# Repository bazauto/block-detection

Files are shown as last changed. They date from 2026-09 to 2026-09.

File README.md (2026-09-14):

# 2-Channel DCC Block Detector (Active High)

CT-based occupancy detection for the Westgate Hollow layout. Two independent
channels, each turning the current in an external current transformer into a
push-pull logic level: **HIGH (3.3 V) = block occupied, LOW (0 V) = clear**.

Single +3.3 V rail, fed in through the output header. Board is **48 × 38 mm**,
2 layers, four M2 mounting holes.

## Why build this

**So that a broken cable or connection under the layout doesn't register as a
clear block.**

The off-the-shelf detectors used so far are active low: they pull their output to
0 V when a block is occupied, and leave it open when clear. The feedback node's
inputs are pulled up, so a broken wire floats high, and that reads exactly like a
clear block, the permissive state (`bazauto/layout-feedback#9`).

This board is **active high**: occupied drives 3.3 V, clear drives 0 V. A broken
wire into a pulled-up input now floats to the *occupied* side.

## Status

**Revision 1.0: 10 boards ordered from PCBWay, awaiting delivery.** Nothing has
been measured on hardware yet.

---

## Files

| File | What it is |
|---|---|
| `bazauto-block-detection.kicad_sch` | Schematic (KiCad 10 format) |
| `bazauto-block-detection.kicad_pcb` | 2-layer PCB, fully routed |
| `bazauto-block-detection.kicad_sym` | Project symbols: `TLV9002IDGKR`, `TLV3212IDGKR` |
| `sym-lib-table` | Project symbol library table. There is no project footprint table: every footprint comes from the stock KiCad libraries and is stored in the board file |
| `bom.csv` | Bill of materials, grouped |
| `fab/rev-1.0/` | **Revision 1.0 as sent to fab**: Gerbers, drill files, Gerber job file, position file, the zipped Gerber set, and `SOURCE.txt` fingerprinting the board they came from. See [Fabrication revisions](#fabrication-revisions) |
| `BOM_PCBWay_bazauto-block-detection.xlsx` | **Not in the repo.** `bom.csv` poured into PCBWay's template, ready to upload. Generate it locally; see [Regenerating](#regenerating) |
| `scripts/` | Generators and checkers — see [Regenerating](#regenerating) |

Everything else (resistors, caps, diodes, connectors, trimmers) comes from the
stock KiCad 10 libraries, so the project opens on any standard install.

---

## Circuit

Each channel is the same chain:

```
CT ─ terminal block ─ burden ─ ESD clamp ─ 1k ─ precision peak detector ─ comparator ─ OUT
     J1 / J2          R1,R2,R3  D1 / D2   R4/R5   U1 + D3/D4 + C3/C4 + R8/R9   U2      J3
                      + JP1
```

**Burden.** The CT secondary is loaded across the input terminals.
Channel 1 is switchable, channel 2 is fixed:

| Channel | JP1 | Burden | Use |
|---|---|---|---|
| 1 | open | 1.1 kΩ | Programming track (service-mode ACK pulse) |
| 1 | fitted | 1.1 k ∥ 110 R = **100.0 Ω** | Standard track |
| 2 | — | 100 Ω fixed | Standard track only |

The parallel combination is exact: 1100 × 110 / 1210 = 100.0 Ω.

**Clamp.** D1/D2 (BAT54S, series pair) clamp the input to roughly −0.3 V /
+3.6 V. R4/R5 (1 k) then limit the current into the op-amp's input structure on
the negative half-cycle — the CT output is bipolar and a single-supply op-amp
input sits at the very edge of its absolute maximum without them.

**Peak detector.** The op-amp drives D3/D4 with the diode *inside* the feedback
loop, so the forward drop is divided out by the loop gain — no 0.6 V loss on a
signal this small. R6/R7 (100 Ω) sit between the op-amp output and the diode:
they are inside the loop too, and stop the RRIO output from ringing into the
10 µF hold capacitor. C3/C4 hold the envelope, R8/R9 bleed it away.

**Comparator.** The envelope goes to +IN, the trimmer wiper to −IN, and the
push-pull output drives the header directly. R10/R11 (10 M) add positive
feedback so the output does not chatter as the envelope crosses the threshold.

---

## Setting up

Time constants and tuning, all measurable on the board:

- **Release time.** R8/R9 × C3/C4 = 100 kΩ × 10 µF ≈ **1 s** to decay. That
  doubles as debounce for dirty wheels. For a faster release drop the bleed
  resistor — 10 k gives ≈ 100 ms.
- **Hysteresis.** V_hyst ≈ 3.3 V × R_bleed / R_hyst = 3.3 × 100 k / 10 M
  ≈ **33 mV**. Lower R10/R11 for more.
- **Threshold.** With the block clear, turn RVn until OUTn just goes low, then
  back off about 10 %.

Test points, all on the top side:

| TP | Net | Use |
|---|---|---|
| TP1 / TP3 | VREF1 / VREF2 | Trimmer wiper — the threshold you have dialled in |
| TP2 / TP4 | ENV1 / ENV2 | Peak-detector output — the rectified envelope |
| TP5 | GND | Scope ground |

---

## ⚠ Known concerns with revision 1.0

**1. The signal chain has no gain, and that makes the threshold hard to set.**

This is the one thing worth changing. The detector is a unity-gain rectifier, so
the comparator threshold has to be set in the millivolt region. With a 1:100 CT
and a 100 Ω burden, 10 mA of track current gives about 10 mV at the envelope
node. The trimmer spans the full 0–3.3 V across 10 kΩ, so 10 mV is **0.3 % of
its travel** — a fraction of one turn on a 12-turn trimmer — and it is the same
order as the comparator's own input offset voltage. Setting it repeatably will
be unpleasant, and it will drift.

The cheap fix is one resistor: put ~330 kΩ in series between +3V3 and the top of
each trimmer (RV1 pin 1, RV2 pin 1). The wiper then covers roughly 0–100 mV
instead of 0–3.3 V, giving about 30× the resolution and swamping nothing else.
The alternative is to give the op-amp stage gain instead of running it at unity.

**Revision 1.0, as ordered, does not include this change** (there is no 330 kΩ
part in `bom.csv`). Sizing it properly needs the CT's actual turns ratio. It
affects two nets and about 4 mm of track.

**2. Verify the TLV3212IDGKR pinout against the datasheet.** The comparator
symbol uses the industry-standard 8-pin dual layout — 1=OUTA, 2=INA−, 3=INA+,
4=GND, 5=INB+, 6=INB−, 7=OUTB, 8=V+ — which is what TLV3202IDGKR uses in the
same DGK package. I could not confirm TLV3212's pin assignment from a datasheet
in this session. **TLV3202IDGKR is a verified drop-in** if you would rather not
check. Same for TLV9002IDGKR, though that one follows the universal dual-op-amp
pinout and is not in doubt.

**3. AGND is the plane, not a separate net.** The spec asked for the filter
returns to go to AGND *and* for a solid, unbroken ground plane. Those pull in
opposite directions — a genuine second net needs a split, and a split is exactly
what section 6 forbids. I used one continuous GND pour and kept the analog
returns physically local instead: C3/C4 and R8/R9 ground through their own vias
straight into the plane, a few millimetres from the op-amp's own ground via.

---

## Layout

- **B.Cu is a ground pour.** F.Cu carries the signals plus a second GND pour in
  the gaps. 30 ground vias tie the two together: 16 taking SMD ground pads
  straight down to the plane, 14 stitching the pours across the board.
- **+3V3** runs as a perimeter ring (top edge, right edge, bottom edge) with a
  spine threaded through the gap between the two pad rows of U1 and U2, so it
  never crosses a channel's signal path.
- The two channels are mirrored top and bottom about the board centreline, with
  the shared dual op-amp and comparator between them. Both ICs are rotated so
  channel A faces the top band and channel B the bottom.
- 0.1 µF decoupling (C1, C2) sits against each IC's V+ pin; C5 is the 10 µF bulk.

**Where the ground plane is interrupted.** Four short bottom-layer hops let
crossing nets pass each other, 8.60 mm of track in total on a 1824 mm² board:

| Net | From → to | Length |
|---|---|---|
| +3V3 | (20.20, 22.00) → (20.20, 24.00) | 2.00 mm |
| /OUT1 | (42.20, 18.30) → (43.80, 18.30) | 1.60 mm |
| /OUT2 | (31.90, 22.60) → (33.45, 22.60) | 1.55 mm |
| OA2 out | (21.50, 22.75) → (21.50, 26.20) | 3.45 mm |

`scripts/check_plane.py` audits this and reports which analog nets pass over a
void. Current result: **the CT input rails, both op-amp inputs, ENV1 and VREF1
have completely unbroken copper beneath them.** Four crossings remain, all in
channel 2's middle band — ENV2 twice, VREF2 once, channel 2's op-amp output
once — and in each the trace crosses a void under 1 mm wide. Those nets carry a
rectified DC envelope and a DC threshold reference, where a sub-millimetre
detour in the return path at DCC frequencies is not a real effect. If you want them gone, the honest fix is a 4-layer stack-up, not
more clever 2-layer routing.

One placement change from your version: **C1 moved 0.65 mm right** (to x = 23.45)
so that channel 2's feedback trace and op-amp output each get their own corridor
past it. Everything else is where you left it.

---

## Regenerating

Run with KiCad's bundled Python, from the project directory:

```sh
K="C:/Program Files/KiCad/10.0"

python scripts/gen_schematic.py         # schematic + project symbol lib
python scripts/verify_netlist.py        # netlist vs. design intent
"$K/bin/python.exe" scripts/route_pcb.py    # routing + pours (placement is preserved)
"$K/bin/python.exe" scripts/check_board.py  # placement + board-vs-schematic nets
"$K/bin/python.exe" scripts/check_plane.py  # ground-plane audit
```

`route_pcb.py` loads the existing board, so hand-adjusted placement and
silkscreen survive; it only rebuilds tracks, vias and zones.

| Script | Does |
|---|---|
| `gen_schematic.py` | Builds the schematic from real KiCad library symbols; wires are computed from actual pin coordinates |
| `kicadlib.py` | S-expression reader/writer and symbol-library helpers |
| `probe_transform.py` | Derives KiCad's symbol placement transform empirically from its own demo files |
| `verify_netlist.py` | Compares the extracted netlist against the intended one, net by net |
| `route_pcb.py` | Routing, ground pours, silkscreen legends |
| `check_board.py` | Courtyard overlaps, off-board parts, board nets vs. schematic |
| `check_plane.py` | Bottom-layer voids and which analog nets cross them |
| `make_pcbway_bom.py` | Fills PCBWay's BOM template; fails if it has drifted from `bom.csv`. Needs PCBWay's sample BOM template saved locally as `Sample_BOM_PCBWay.xlsx`. It's PCBWay's file, so it isn't committed, and neither is the output. |
| `check_fab_outputs.py` | Checks the newest `fab/rev-X.Y/` against the board it was generated from; `--record` writes that revision's `SOURCE.txt`. Plain Python, needs `kicad-cli` on PATH or `KICAD_CLI` set |

---

## Fabrication revisions

Each set of files sent to a board house lives in its own `fab/rev-X.Y/` folder
and is never regenerated in place, so the repo always holds exactly what a
revision was. Each revision is also tagged in git (`rev-1.0`).

`fab/rev-X.Y/SOURCE.txt` records the SHA-256 of the board file (line endings
normalised) that its outputs came from. CI runs `scripts/check_fab_outputs.py`:

- **Board unchanged since the newest revision:** it regenerates the outputs and
  fails if the committed ones differ. That catches Gerbers left stale after a
  board edit, and a zip that disagrees with the loose files. Gerbers are compared
  by the geometry they draw, because KiCad doesn't write primitives in a stable
  order.
- **Board changed:** work on the next revision is under way. It reports a notice
  and passes.

To cut a new revision, for example 1.1:

1. Plot Gerbers, drill files (Excellon, PTH and NPTH separate) and the position
   file (CSV, mm, both sides) into `fab/rev-1.1/`, and zip the Gerbers, the
   Gerber job file and the drill files as `bazauto-block-detection.zip` there.
2. `python scripts/check_fab_outputs.py --record rev-1.1`
3. `python scripts/check_fab_outputs.py`, which must report all outputs matching.
4. Land it through a PR, then tag the merge commit `rev-1.1`.

---

## Verification

Everything below was run against the files in this directory:

```
kicad-cli sch erc            0 errors, 0 warnings
verify_netlist.py            all 17 nets match design intent, no unconnected pins
kicad-cli pcb drc            0 violations, 0 unconnected items
check_board.py               37 footprints, 0 problems (no overlaps, nets match schematic)
check_plane.py               8.60 mm bottom-layer track; 4 analog crossings (see above)
```

CI re-runs the two `kicad-cli` checks and `check_fab_outputs.py` on every pull
request (see `.github/workflows/ci.yml`). DRC there runs with `--schematic-parity` at error
severity. At warning severity the parity check reports 80 cosmetic mismatches:
footprints saved without their library prefix, and field text such as a
Datasheet of `''` against `~`. None is a net or connection mismatch.

Gerbers and drill files for revision 1.0 are in `fab/rev-1.0/`, and regenerating
them from the current board reproduces them exactly. Nothing has been measured on
hardware yet. The threshold-resolution concern above is analysis, not a bench
result.

---

## Licence

Copyright © 2026 Paul Barrett.

| Material | Licence |
|---|---|
| **The hardware design**: schematic, board, project symbol library, BOM, Gerbers and drill files, and the enclosure model (`enclosure/`, except `check_fit.py`) | [CERN-OHL-P-2.0](LICENSE) |
| **Software**: everything in `scripts/`, and `enclosure/check_fit.py` | [MIT](LICENSE-MIT) |

Source location: <https://github.com/bazauto/block-detection>

Third-party material, notably the KiCad library symbols the project symbols are
derived from, is listed in [THIRD-PARTY-NOTICES.md](THIRD-PARTY-NOTICES.md).

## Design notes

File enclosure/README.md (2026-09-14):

# Enclosure — 2-Channel DCC Block Detector

3D-printed DIN-rail box for the 48 × 38 mm block-detector PCB in the parent
directory. Three parts, all printable without supports.

**Outer size 62.0 × 52.0 × 32.6 mm**, plus the rail clip underneath.

| Part | STL | Prints |
|---|---|---|
| Box body | `stl/block-detector-base.stl` | floor down, as modelled |
| Lid | `stl/block-detector-lid.stl` | outside face down, as modelled |
| DIN TH35 clip | `stl/block-detector-clip.stl` | mating face down, as modelled |

Everything comes from one parametric source, `block-detector-enclosure.scad`.
`check_fit.py` audits the clearances against the actual KiCad board.

---

## How it goes together

The rail runs along the box's **52 mm axis**, so modules stack side by side
along the rail and every cable leaves through an end wall, not into the
neighbouring module.

- **Left wall** — two slots, one per CT terminal block. J1/J2 are Phoenix PT
  push-in blocks with the wire entry facing the wall, 5 mm behind it. Thread
  the CT leads through the slot before landing them.
- **Right wall** — one slot for the OUT cable, sitting high enough that the
  1×4 housing on J3 passes underneath it and the wires turn out over the top.
- **Board** sits on four 5 mm standoffs, 7 mm above the floor, screwed down at
  its own M2 holes. 22 mm of clear height above it.
- **Lid** has a register lip and four countersunk M3 screws into corner posts.
  Solid — take it off to set the thresholds on RV1/RV2 or move the MODE jumper.

### Hardware

| Qty | Screw | Into |
|---|---|---|
| 4 | M3 × 10 countersunk, self-tapping | lid → corner posts (2.5 mm pilot) |
| 4 | M2 × 6 pan head, self-tapping | board → standoffs (1.6 mm pilot) |
| 2 | M3 × 8 countersunk, self-tapping | DIN clip → box floor (2.5 mm pilot) |

Plain machine screws work as well as self-tappers — they cut their own thread
in the printed pilot holes. Do not over-torque the M2s; the standoffs are
5 mm tall and 5 mm across.

### The DIN clip

Screws to the outside of the box floor, so the box can be re-mounted flat later
by printing a different back plate. One hook is fixed, the other is a 35 mm
spring tongue with a release tab at one end — hook the fixed side over the rail
first, then push until the tongue snaps home. To remove, lever the tab away
from the rail with a small screwdriver.

The channel is 34.6 mm across a 35 mm rail, so the tongue is preloaded and the
module does not rattle. Clipping on needs 2.2 mm of tongue throw.

**Print the clip in PETG** if you have it. The tongue is a living spring and PLA
loses that over time.

---

## Print settings

0.2 mm layers, 3 perimeters, 4 top/bottom, 30 % infill. No supports on any part
— every overhang is either a 45° chamfer or a bridge under 13 mm.

The lid is designed to print with the **outside face on the bed**, so the
lettering is engraved rather than raised and comes out crisp on the first
layers. The `part="lid"` and `part="clip"` outputs are already in their print
orientation; drop the STLs straight into the slicer.

---

## Re-cutting the model

```sh
SCAD="/c/Program Files/OpenSCAD/openscad.exe"

# view it
"$SCAD" block-detector-enclosure.scad

# the printable parts
for p in base lid clip; do
  "$SCAD" -o "stl/block-detector-$p.stl" -D "part=\"$p\"" block-detector-enclosure.scad
done

# check nothing collides after changing a parameter
python check_fit.py
```

`part` also takes `assembly` (box + lid + clip + board + rail), `fit` (board in
the open box) and `section_x` / `section_y` with `section_at` for cutaways.

### Parameters worth touching

| Parameter | Default | Why you would change it |
|---|---|---|
| `headroom` | 22 | Clear height over the board. Set by the 1×4 Dupont housing on J3 (~17 mm) plus room for the wires to turn. Solder the OUT cable straight to the pins and 12 is enough — that takes 10 mm off the box height. |
| `pcb_gap` | 4.6 | Board edge to wall. Driven by the corner posts having to miss the board corners; below ~4.3 they clash. |
| `corner_r` | 4.5 | Outer corner radius. The lid screws sit on this axis, so it also sets the wall left around their countersinks. Do not go below ~4.4 with M3. |
| `spring_preload` | 0.5 | How hard the DIN tongue bears on the rail. Raise it if the module rattles, lower it if it will not clip on. |
| `rail_brim_t` | 1.0 | Rail sheet thickness. Heavy rail is 1.35 — set it and the hooks follow. |

`check_fit.py` reads these straight out of the `.scad`, so run it after any
change. Current result:

```
Enclosure  62.0 x 52.0 x 32.6 mm outer   (interior 57.2 x 47.2 x 28.6)
Board sits 7.0 mm above the floor, 22.0 mm clear above it under the lid.
read 28 component courtyards from the board file
all 37 checks pass
```

Tightest clearances it reports: 0.54 mm between each corner post and the board
corner, 3.77 mm from the M2 screw heads to the RV1/RV2 courtyards, and 1.30 mm
of wall outboard of the lid countersinks.

---

## Not done

Nothing has been printed or measured. The connector heights used to size the
box are nominal — in particular `headroom` assumes a generic 2.54 mm Dupont
housing at about 17 mm above the board. Measure yours before printing; it is
one parameter and the box height follows it directly.

The CT slots assume the Phoenix PT-1,5-2-3.5-H wire axes sit about 4.5 mm above
the board. The slots are 7.5 × 8.5 mm and centred on that, so a couple of
millimetres either way is absorbed.

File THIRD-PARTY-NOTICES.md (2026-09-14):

# Third-party notices

## KiCad libraries: CC-BY-SA 4.0, with a design exception

The schematic and board use symbols and footprints from the stock KiCad 10 libraries, by the KiCad Libraries Team
(<https://gitlab.com/kicad/libraries>). Those libraries are licensed under
[CC-BY-SA 4.0](https://creativecommons.org/licenses/by-sa/4.0/) with this exception:

> To the extent that the creation of electronic designs that use 'Licensed Material' can be considered to be
> 'Adapted Material', then the copyright holder waives article 3 of the license with respect to these designs and any
> generated files which use data provided as part of the 'Licensed Material'.

So the design itself and its generated files (Gerbers, drill files, position file) carry no CC-BY-SA obligation, and
are licensed under CERN-OHL-P-2.0 as stated in the README.

### Project symbols derived from KiCad library symbols

`bazauto-block-detection.kicad_sym` is generated by `scripts/gen_schematic.py`. It copies two stock symbols, renames
them, and changes their properties:

| Project symbol | Derived from |
|---|---|
| `TLV9002IDGKR` | `Amplifier_Operational:LM2904` |
| `TLV3212IDGKR` | `Comparator:MCP6562` |

These are attributed here as adaptations of KiCad library material (KiCad Libraries Team, CC-BY-SA 4.0). The design
exception above very likely covers a symbol library generated for this design, but attribution costs nothing and
holds under either reading.

## Not in the repository

- **PCBWay's BOM template** (`Sample_BOM_PCBWay.xlsx`) and the upload BOM generated from it are PCBWay's format with
  no licence to redistribute, so both are git-ignored and kept locally. `bom.csv` is the source of truth.
- **PCBWay order paperwork** (`PCBWay/`) is git-ignored.

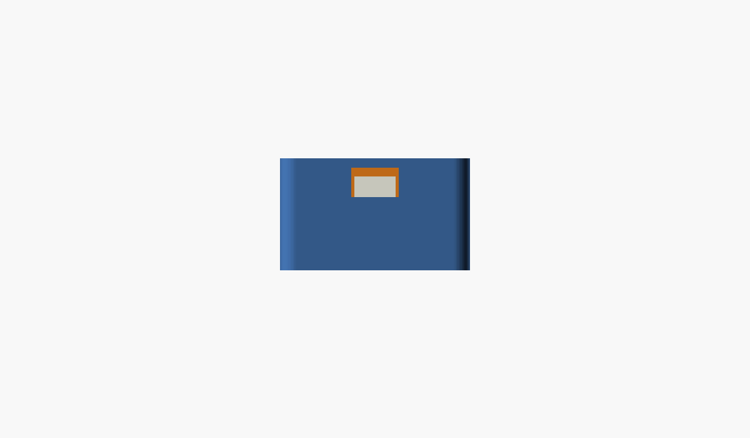
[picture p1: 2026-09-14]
enclosure/previews/fit_right.png

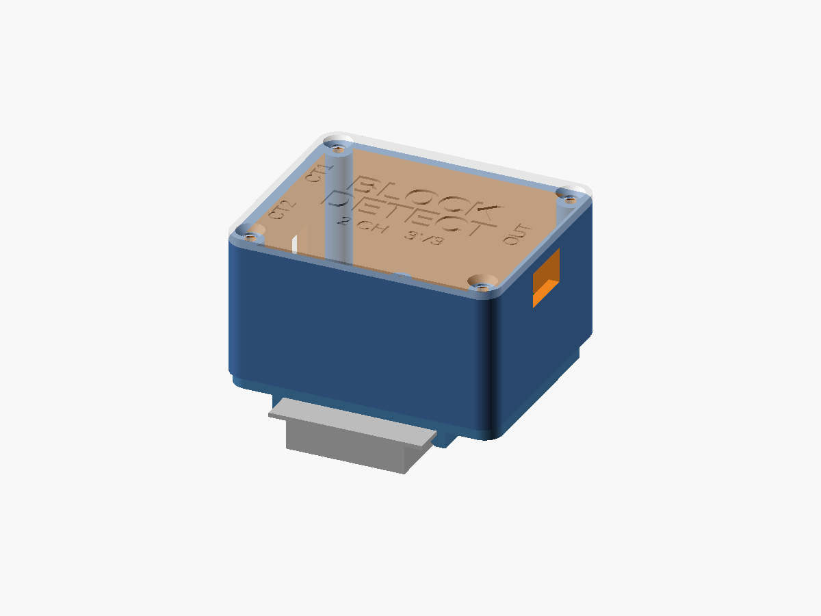
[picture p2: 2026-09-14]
enclosure/previews/asm_iso2.png

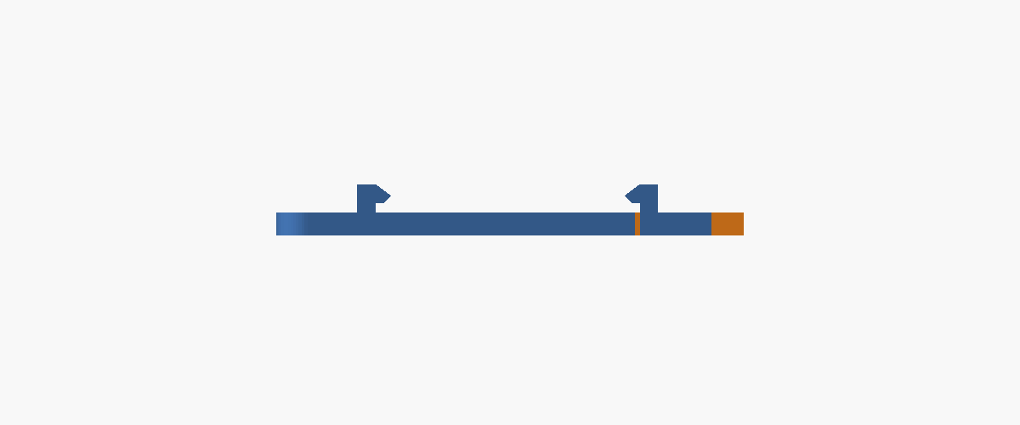
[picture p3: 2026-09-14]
enclosure/previews/clip_end.png

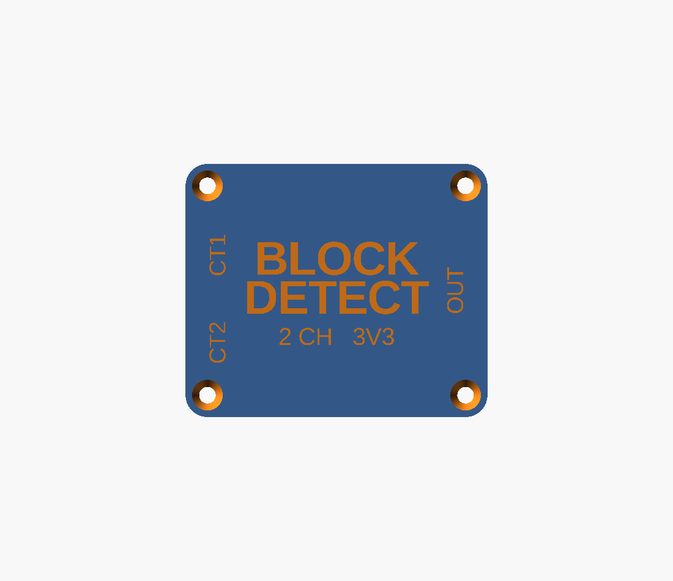
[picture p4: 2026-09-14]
enclosure/previews/lid_top.png

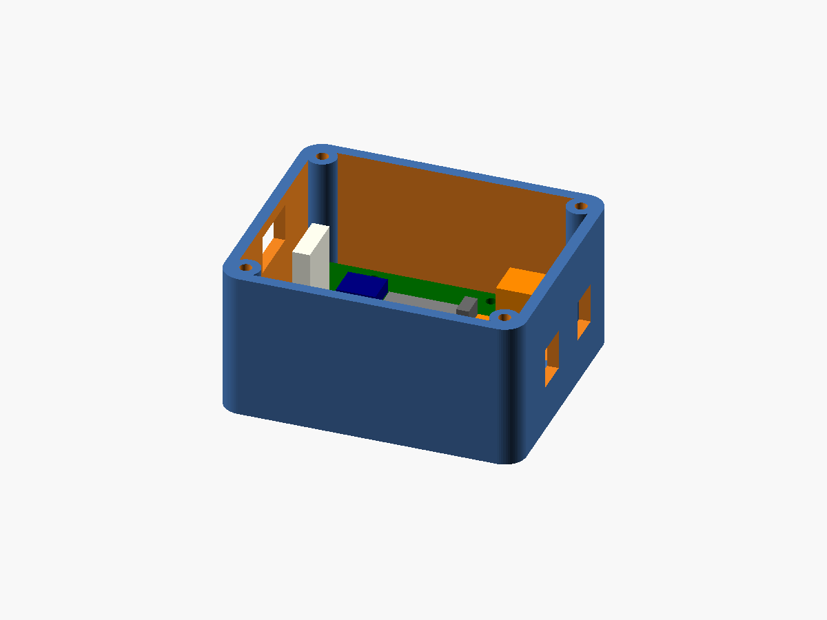
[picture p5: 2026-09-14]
enclosure/previews/fit_iso.png

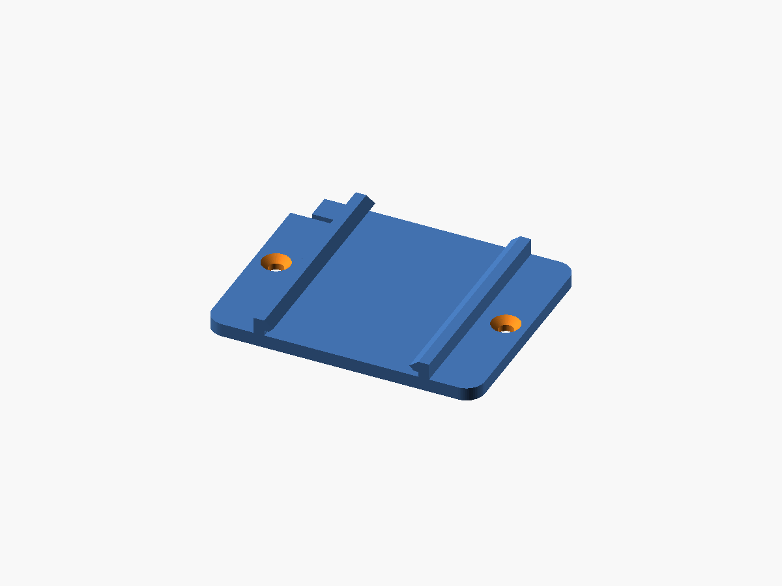
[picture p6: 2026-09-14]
enclosure/previews/clip_iso.png

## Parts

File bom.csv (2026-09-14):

Refs | Value | Footprint | Tolerance | Rating | Description | Alternative Part Number
C1,C2 | 100nF | Capacitor_SMD:C_0805_2012Metric |  | 25V
C3-C5 | 10uF | Capacitor_SMD:C_0805_2012Metric |  | 25V
D1,D2 | BAT54S | Package_TO_SOT_SMD:SOT-23
D3,D4 | 1N4148W | Diode_SMD:D_SOD-123
J1 | CT1 In | TerminalBlock_Phoenix:TerminalBlock_Phoenix_PT-1,5-2-3.5-H_1x02_P3.50mm_Horizontal
J2 | CT2 In | TerminalBlock_Phoenix:TerminalBlock_Phoenix_PT-1,5-2-3.5-H_1x02_P3.50mm_Horizontal
J3 | OUT | Connector_PinHeader_2.54mm:PinHeader_1x04_P2.54mm_Vertical
JP1 | MODE | Connector_PinHeader_2.54mm:PinHeader_1x02_P2.54mm_Vertical
R1 | 1.1k | Resistor_SMD:R_1206_3216Metric | 1%
R2 | 110R | Resistor_SMD:R_1206_3216Metric | 1%
R3 | 100R | Resistor_SMD:R_1206_3216Metric | 1%
R4,R5 | 1k | Resistor_SMD:R_0805_2012Metric
R6,R7 | 100R | Resistor_SMD:R_0805_2012Metric
R8,R9 | 100k | Resistor_SMD:R_0805_2012Metric
R10,R11 | 10M | Resistor_SMD:R_0805_2012Metric
RV1,RV2 | 10k | Potentiometer_SMD:Potentiometer_Bourns_3269W_Vertical
U1 | TLV9002IDGKR | Package_SO:MSOP-8_3x3mm_P0.65mm
U2 | TLV3212IDGKR | Package_SO:MSOP-8_3x3mm_P0.65mm |  |  |  | TLV7012DGKR

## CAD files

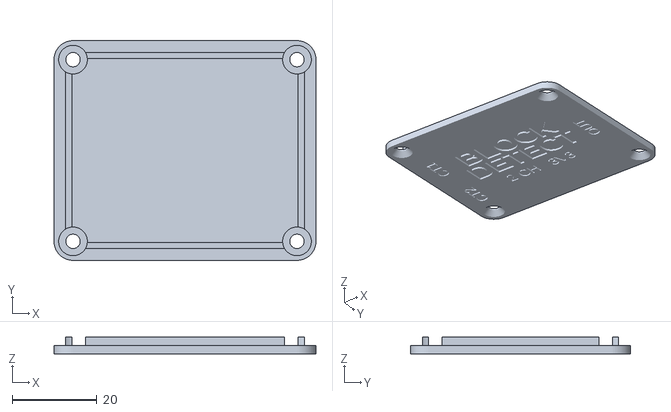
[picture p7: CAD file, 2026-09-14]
enclosure/stl/block-detector-lid.stl
62.0 x 52.0 x 4.00

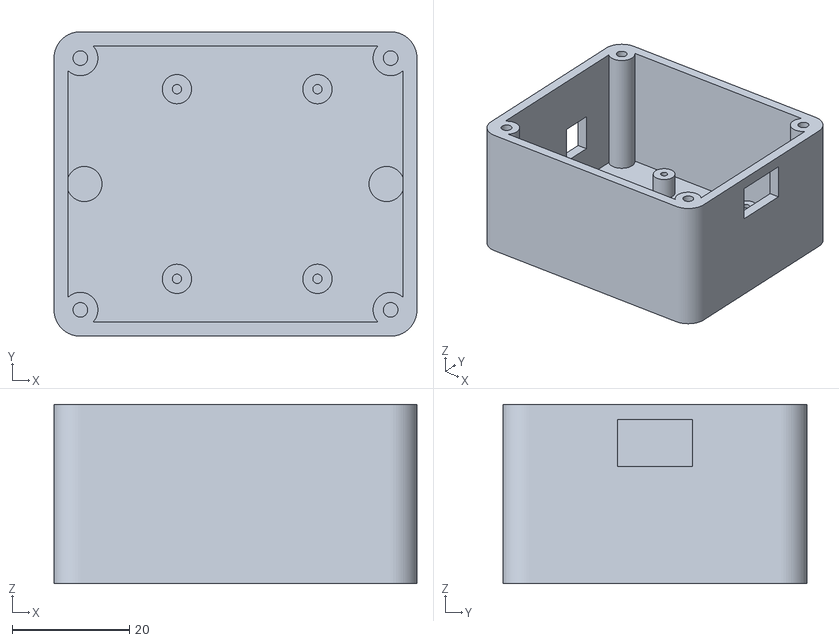
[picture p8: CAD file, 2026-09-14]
enclosure/stl/block-detector-base.stl
62.0 x 52.0 x 30.6

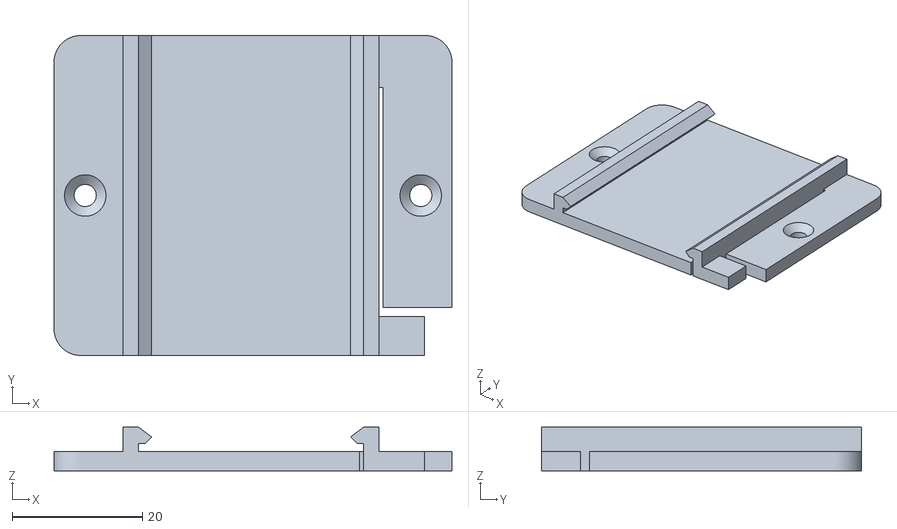
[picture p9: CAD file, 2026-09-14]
enclosure/stl/block-detector-clip.stl
61.2 x 49.2 x 6.70

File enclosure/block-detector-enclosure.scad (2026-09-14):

// ============================================================================
//  Enclosure for the bazauto 2-Channel DCC Block Detector
//  PCB: 48 x 38 x 1.6 mm, 4 x M2 mounting holes.
//
//  Three printed parts, selected with the "part" variable below:
//    base  - box body, prints floor-down, no supports
//    lid   - solid lid, prints outside-face-down, no supports
//    clip  - DIN TH35 rail clip, prints mating-face-down, no supports
//
//  Orientation in the model: X is the PCB's 48 mm axis, Y its 38 mm axis,
//  Z up out of the board. The DIN rail runs along Y, so modules stack along
//  the rail and every cable leaves through an X-facing wall.
// ============================================================================

part = "assembly";  // [base, lid, clip, assembly, section_x, section_y]
section_at = 30;    // cut plane, used by the section views only

// ---------------------------------------------------------------- PCB facts
pcb_w        = 48.0;    // board X
pcb_d        = 38.0;    // board Y
pcb_t        = 1.6;     // board thickness
pcb_hole_d   = 2.2;     // M2 clearance holes in the board
pcb_holes    = [[14, 2.8], [14, 35.2], [38, 2.8], [38, 35.2]];

// Connector positions, in board coordinates (origin = board lower-left corner)
j1_wire_y    = [24.5, 28.0];   // CT1 terminal block, wire axes
j2_wire_y    = [ 6.5, 10.0];   // CT2 terminal block, wire axes
j3_y         = [15.19, 22.81]; // OUT header, pin 1 .. pin 4

// ------------------------------------------------------------- Box envelope
pcb_gap      = 4.6;     // board edge to interior wall
wall         = 2.4;
floor_t      = 2.0;
lid_t        = 2.0;
standoff_h   = 5.0;     // board underside above the floor (clears THT leads)
headroom     = 22.0;    // clear height above the board, under the lid.
                        //   Set by the 1x4 Dupont housing on J3 (~17 mm) plus
                        //   room for the wires to turn out through the wall.
                        //   Solder the cable direct and 12 is enough.
corner_r     = 4.5;     // outer corner radius. The lid screws sit on this
                        //   axis, so it also sets the wall left around their
                        //   countersinks - do not reduce it below ~4.4.

// ------------------------------------------------------------------ Fixings
lid_pilot_d   = 2.5;    // M3 self-tapping into the corner posts
lid_clear_d   = 3.4;
lid_cs_d      = 6.4;    // countersink major diameter
post_r        = 3.0;    // screw axis sits at the centre of the corner radius,
                        //   which is the point furthest from the outer surface

pcb_screw_pilot_d = 1.6; // M2 self-tapping into the board standoffs
pcb_standoff_r    = 2.5;

clip_screw_pilot_d = 2.5; // M3 self-tapping, clip -> box floor
clip_boss_r        = 3.0;

lip_h        = 2.0;     // lid register lip
lip_w        = 1.5;
lip_clear    = 0.35;

// ------------------------------------------------------------- DIN TH35 clip
clip_plate_t = 3.0;
rail_w       = 35.0;    // brim-to-brim width of a TH35 rail
rail_brim_t  = 1.0;     // brim sheet thickness
brim_slop    = 0.2;
spring_preload = 0.5;   // interference the spring tongue must take up
clip_wall_t  = 2.4;
lip_reach    = 2.0;     // how far the hooks reach in under the brims
clip_margin  = 0.4;     // clip plate inset from the box outline
anchor_len   = 8.0;     // rooted length of the spring tongue
tab_len      = 6.0;
tab_reach    = 7.0;

// --------------------------------------------------------------- Derived
interior_w = pcb_w + 2*pcb_gap;              // 55.0
interior_d = pcb_d + 2*pcb_gap;              // 45.0
interior_h = standoff_h + pcb_t + headroom;  // 28.6
outer_w    = interior_w + 2*wall;            // 59.8
outer_d    = interior_d + 2*wall;            // 49.8
base_h     = floor_t + interior_h;           // 30.6
outer_h    = base_h + lid_t;                 // 32.6
interior_r = max(corner_r - wall, 0.6);

pcb_x0 = wall + pcb_gap;                     // board origin in box coords
pcb_y0 = wall + pcb_gap;
pcb_z0 = floor_t + standoff_h;               // board underside
pcb_zt = pcb_z0 + pcb_t;                     // board top

post_xy = [[corner_r,           corner_r],
           [outer_w - corner_r, corner_r],
           [corner_r,           outer_d - corner_r],
           [outer_w - corner_r, outer_d - corner_r]];

// Clip screws sit in the two bands the rail channel leaves free, clear of the
// spring tongue's slot on one side and the fixed hook on the other.
clip_boss_xy = [[5.2, outer_d/2], [outer_w - 5.2, outer_d/2]];
clip_boss_h  = standoff_h - 0.6;             // stops just under the board

rail_cx      = outer_w/2;
fixed_in     = rail_cx - rail_w/2 - brim_slop/2;
fixed_out    = fixed_in - clip_wall_t;
spring_in    = rail_cx + rail_w/2 - spring_preload;
spring_out   = spring_in + clip_wall_t;

clip_x0 = clip_margin;              clip_x1 = outer_w - clip_margin;
clip_y0 = clip_margin + 1.0;        clip_y1 = outer_d - clip_margin - 1.0;
clip_corner_r = max(corner_r - clip_margin, 1.0);

$fn = 64;

// ============================================================================
//  Helpers
// ============================================================================
module rrect(w, d, r) {
    translate([r, r]) offset(r = r) square([w - 2*r, d - 2*r]);
}

module outer_profile()    { rrect(outer_w, outer_d, corner_r); }
module interior_profile() { translate([wall, wall]) rrect(interior_w, interior_d, interior_r); }

// Countersunk clearance hole, drilled downward from z = top.
module countersunk(top, depth) {
    translate([0, 0, top - depth]) cylinder(h = depth + 0.1, d = lid_clear_d);
    translate([0, 0, top - (lid_cs_d - lid_clear_d)/2])
        cylinder(h = (lid_cs_d - lid_clear_d)/2 + 0.05, d1 = lid_clear_d, d2 = lid_cs_d);
}

// ============================================================================
//  Base
// ============================================================================
module base() {
    difference() {
        union() {
            // shell
            difference() {
                linear_extrude(base_h) outer_profile();
                translate([0, 0, floor_t])
                    linear_extrude(interior_h + 1) interior_profile();
            }
            // lid screw posts, blended into the corners
            for (p = post_xy)
                translate([p[0], p[1], floor_t]) cylinder(h = interior_h, r = post_r);
            // PCB standoffs
            for (h = pcb_holes)
                translate([pcb_x0 + h[0], pcb_y0 + h[1], floor_t])
                    cylinder(h = standoff_h, r = pcb_standoff_r);
            // bosses for the DIN clip screws (they live under the board)
            for (p = clip_boss_xy)
                translate([p[0], p[1], floor_t]) cylinder(h = clip_boss_h, r = clip_boss_r);
        }

        // lid screw pilots
        for (p = post_xy)
            translate([p[0], p[1], base_h - 12]) cylinder(h = 12.1, d = lid_pilot_d);

        // PCB screw pilots (blind, 1 mm of floor left)
        for (h = pcb_holes)
            translate([pcb_x0 + h[0], pcb_y0 + h[1], 1.0])
                cylinder(h = standoff_h + floor_t - 1.0 + 0.01, d = pcb_screw_pilot_d);

        // DIN clip screw pilots, right through the floor
        for (p = clip_boss_xy)
            translate([p[0], p[1], -0.1])
                cylinder(h = floor_t + clip_boss_h - 0.4 + 0.1, d = clip_screw_pilot_d);

        wall_openings();
    }
}

// Cable slots. Left wall: the two CT terminal blocks. Right wall: the OUT cable.
module wall_openings() {
    slot_z0 = pcb_zt + 0.9;
    slot_z1 = pcb_zt + 9.4;

    // CT1 / CT2, one slot each, centred on the pair of wire axes
    for (ys = [j1_wire_y, j2_wire_y]) {
        y0 = pcb_y0 + ys[0] - 2.0;
        y1 = pcb_y0 + ys[1] + 2.0;
        translate([-1, y0, slot_z0]) cube([wall + 1.6, y1 - y0, slot_z1 - slot_z0]);
    }

    // OUT cable, high on the right wall so it clears the connector housing
    oy0 = pcb_y0 + j3_y[0] - 2.6;
    oy1 = pcb_y0 + j3_y[1] + 2.6;
    translate([outer_w - wall - 0.6, oy0, pcb_zt + 11.4])
        cube([wall + 1.6, oy1 - oy0, 8.0]);
}
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

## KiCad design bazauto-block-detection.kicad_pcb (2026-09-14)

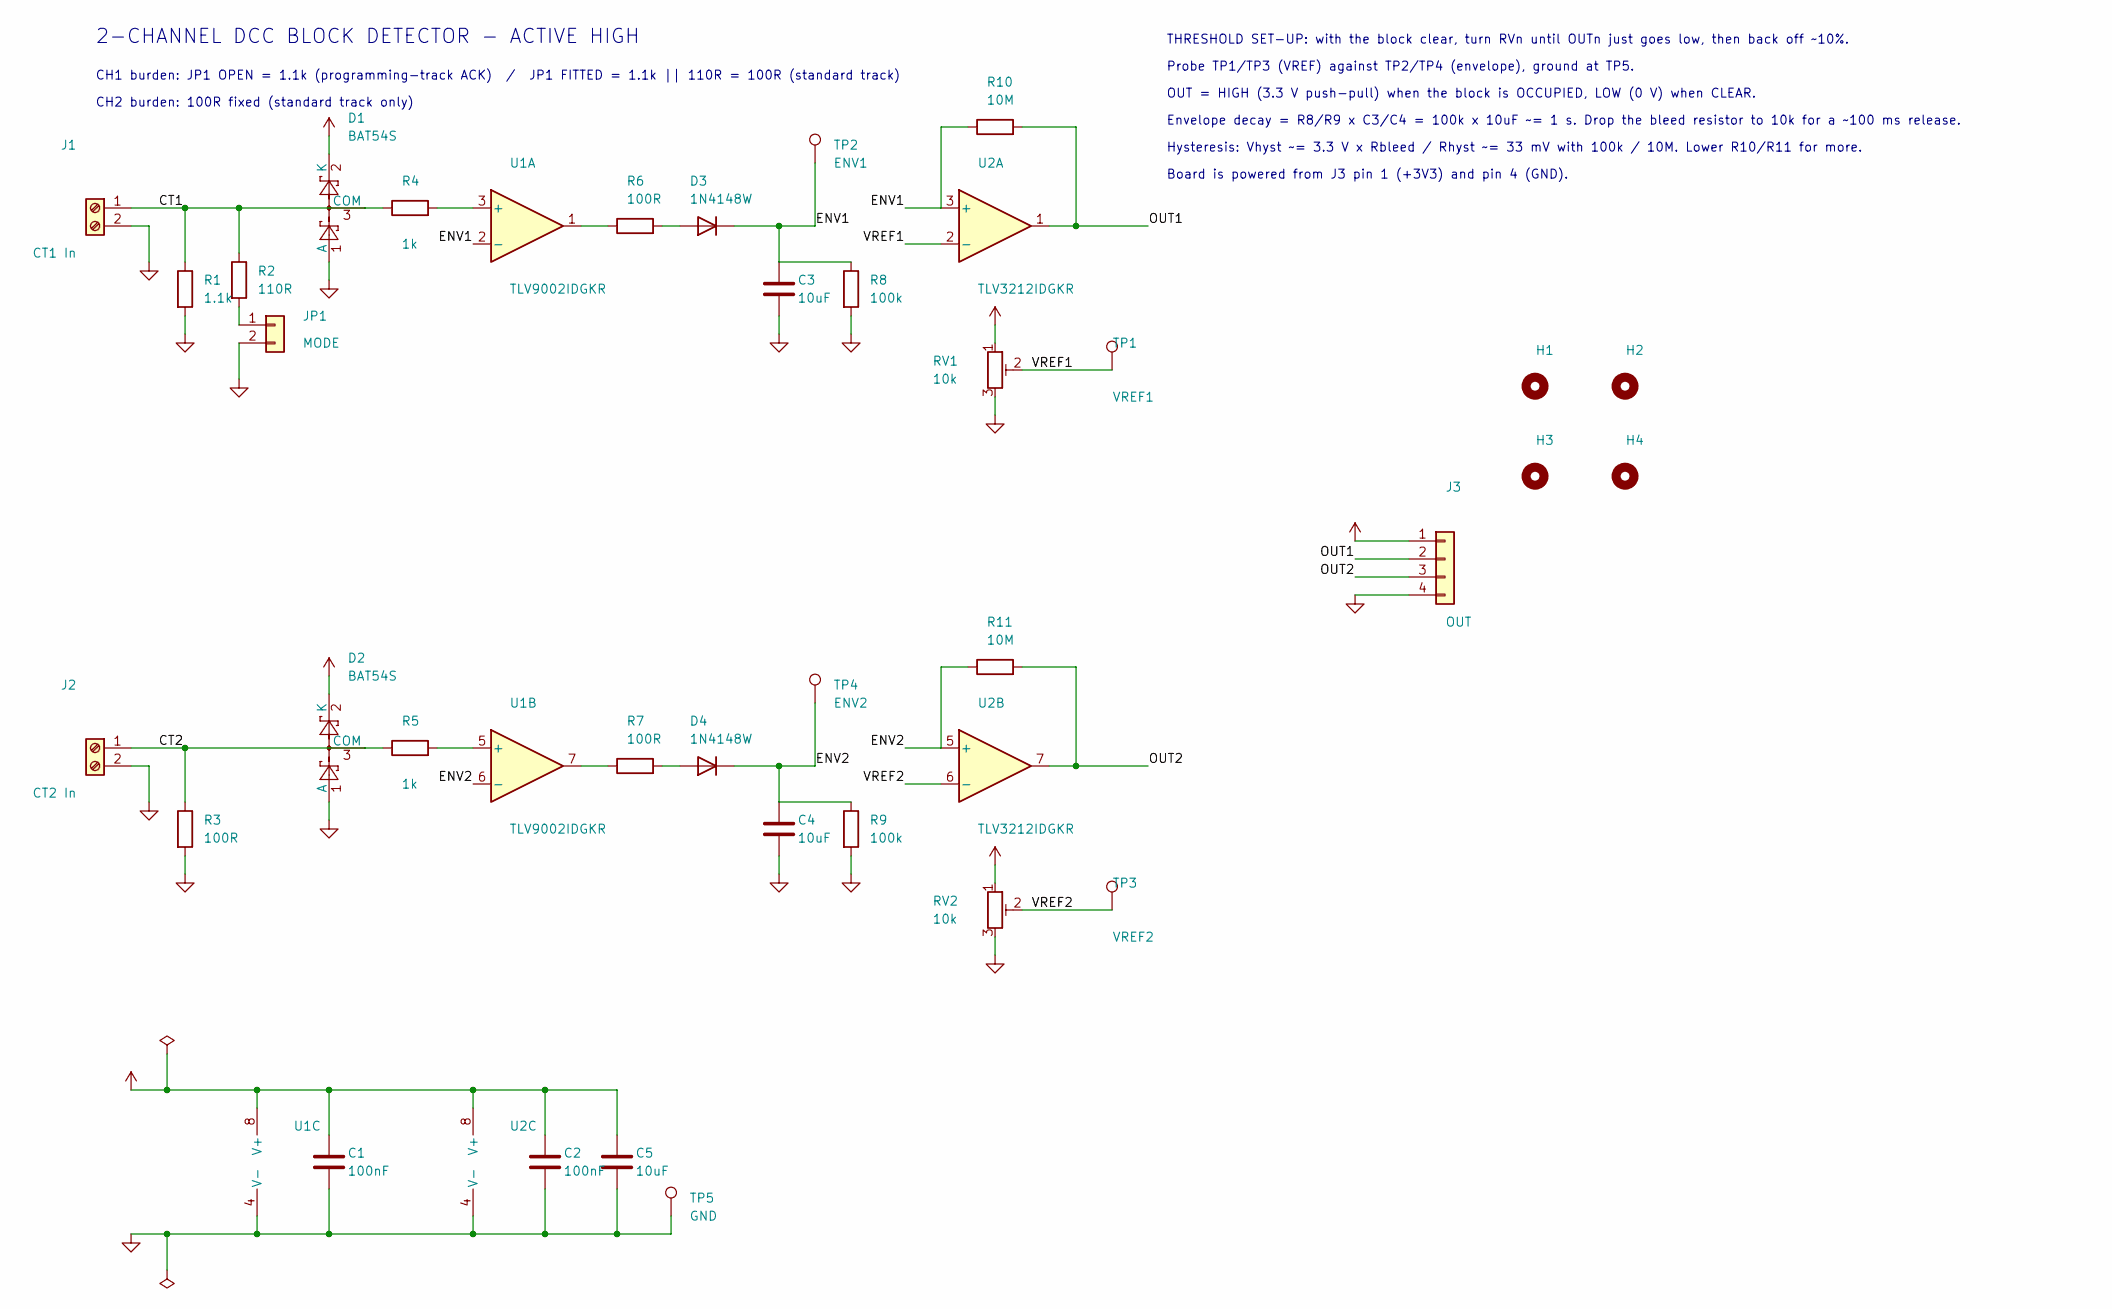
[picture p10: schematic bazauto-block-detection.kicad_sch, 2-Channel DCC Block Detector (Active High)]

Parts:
C1, C2: 100nF; C_0805_2012Metric; Voltage 25V
C3, C4, C5: 10uF; C_0805_2012Metric; Voltage 25V
D1, D2: BAT54S; SOT-23
D3, D4: 1N4148W; D_SOD-123
H1, H2, H3, H4: MountingHole; MountingHole_2.2mm_M2
J1: CT1 In; TerminalBlock_Phoenix_PT-1,5-2-3.5-H_1x02_P3.50mm_Horizontal
J2: CT2 In; TerminalBlock_Phoenix_PT-1,5-2-3.5-H_1x02_P3.50mm_Horizontal
J3: OUT; PinHeader_1x04_P2.54mm_Vertical
JP1: MODE; PinHeader_1x02_P2.54mm_Vertical
R1: 1.1k; R_1206_3216Metric; Tolerance 1%
R2: 110R; R_1206_3216Metric; Tolerance 1%
R3: 100R; R_1206_3216Metric; Tolerance 1%
R4, R5: 1k; R_0805_2012Metric
R6, R7: 100R; R_0805_2012Metric
R8, R9: 100k; R_0805_2012Metric
R10, R11: 10M; R_0805_2012Metric
RV1, RV2: 10k; Potentiometer_Bourns_3269W_Vertical
TP1: VREF1; TestPoint_Pad_D1.5mm
TP2: ENV1; TestPoint_Pad_D1.5mm
TP3: VREF2; TestPoint_Pad_D1.5mm
TP4: ENV2; TestPoint_Pad_D1.5mm
TP5: GND; TestPoint_Pad_D1.5mm
U1: TLV9002IDGKR; MSOP-8_3x3mm_P0.65mm
U2: TLV3212IDGKR; MSOP-8_3x3mm_P0.65mm

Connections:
+3V3: C1.1, C2.1, C5.1, D1.2 (K), D2.2 (K), J3.1, RV1.1, RV2.1, U1.8 (V+), U2.8 (V+)
/CT1: D1.3 (COM), J1.1, R1.1, R2.1, R4.1
/CT2: D2.3 (COM), J2.1, R3.1, R5.1
/ENV1: C3.1, D3.1 (K), R8.1, R10.1, TP2.1, U1.2 (-), U2.3 (+)
/ENV2: C4.1, D4.1 (K), R9.1, R11.1, TP4.1, U1.6 (-), U2.5 (+)
/OUT1: J3.2, R10.2, U2.1
/OUT2: J3.3, R11.2, U2.7
/VREF1: RV1.2, TP1.1, U2.2 (-)
/VREF2: RV2.2, TP3.1, U2.6 (-)
GND: C1.2, C2.2, C3.2, C4.2, C5.2, D1.1 (A), D2.1 (A), J1.2, J2.2, J3.4, JP1.2, R1.2, R3.2, R8.2, R9.2, RV1.3, RV2.3, TP5.1, U1.4 (V-), U2.4 (V-)
unnamed: D3.2 (A), R6.2
unnamed: D4.2 (A), R7.2
unnamed: JP1.1, R2.2
unnamed: R6.1, U1.1
unnamed: R7.1, U1.7
unnamed: R4.2, U1.3 (+)
unnamed: R5.2, U1.5 (+)

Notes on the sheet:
2-CHANNEL DCC BLOCK DETECTOR - ACTIVE HIGH
CH1 burden: JP1 OPEN = 1.1k (programming-track ACK) / JP1 FITTED = 1.1k || 110R = 100R (standard track)
CH2 burden: 100R fixed (standard track only)
THRESHOLD SET-UP: with the block clear, turn RVn until OUTn just goes low, then back off ~10%.
Probe TP1/TP3 (VREF) against TP2/TP4 (envelope), ground at TP5.
OUT = HIGH (3.3 V push-pull) when the block is OCCUPIED, LOW (0 V) when CLEAR.
Envelope decay = R8/R9 x C3/C4 = 100k x 10uF ~= 1 s. Drop the bleed resistor to 10k for a ~100 ms release.
Hysteresis: Vhyst ~= 3.3 V x Rbleed / Rhyst ~= 33 mV with 100k / 10M. Lower R10/R11 for more.
Board is powered from J3 pin 1 (+3V3) and pin 4 (GND).

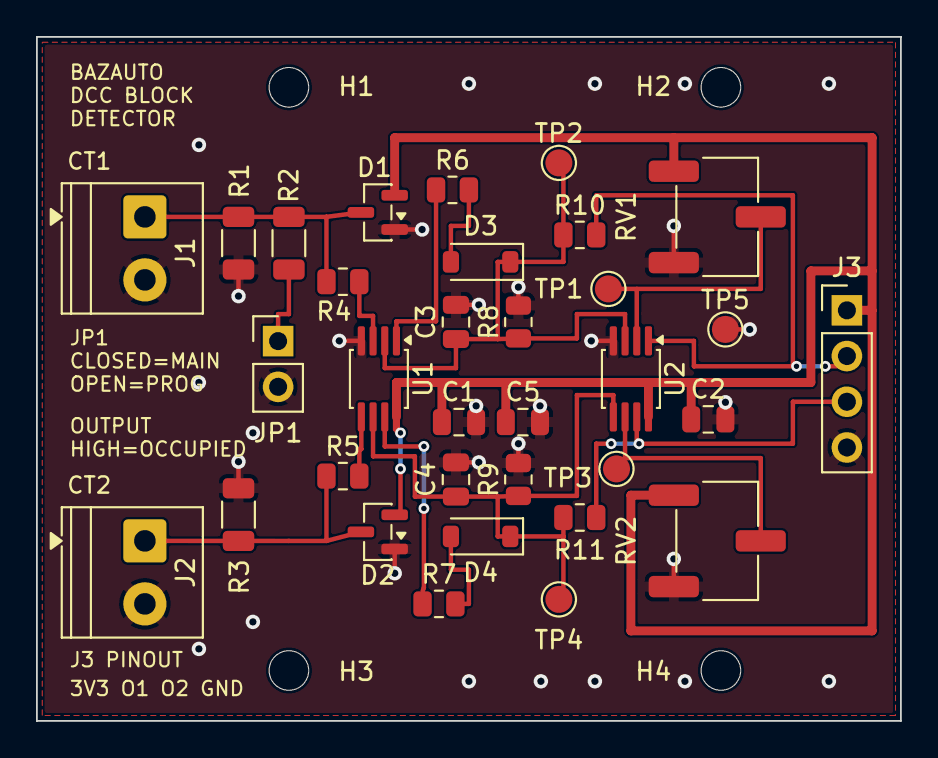
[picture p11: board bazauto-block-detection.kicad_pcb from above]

Board: 2 copper layers, 48.0 x 38.0 mm, 37 parts (0 on the bottom side), 17 nets.

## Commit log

2026-09-14 Import revision 1.0 of the block detector board, with ERC/DRC CI (#1)
    * Import revision 1.0 of the block detector board, with ERC/DRC CI
    KiCad 10 schematic, routed 2-layer board, project symbols, generator and
    checker scripts, BOMs, rev 1.0 Gerbers, and the 3D-printed DIN-rail
    enclosure. PCBWay order paperwork, KiCad backups and local tool state are
    ignored and stay local.
    CI runs kicad-cli ERC at every severity and DRC with schematic parity at
    error severity in the kicad/kicad:10.0.5 image.
    The README now says why the board exists (active high, so a broken cable
    reads as occupied rather than clear), that rev 1.0 boards are on order,
    and that the suggested 330k threshold change is not in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
    [BOM_PCBWay_bazauto-block-detection.xlsx, Sample_BOM_PCBWay.xlsx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]
2026-09-14 License the design CERN-OHL-P-2.0 and the scripts MIT (#3)
    The repo had no licence. The hardware design and enclosure are
    CERN-OHL-P-2.0; scripts/ and enclosure/check_fit.py are MIT, matching
    the other bazauto repos.
    THIRD-PARTY-NOTICES.md records the KiCad library exception and
    attributes the two project symbols derived from stock KiCad symbols.
    PCBWay's BOM template, and the upload BOM generated from it, are
    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
    [BOM_PCBWay_bazauto-block-detection.xlsx, Sample_BOM_PCBWay.xlsx]
2026-09-14 Move rev 1.0 fab outputs to fab/rev-1.0, check them in CI, add CLAUDE.md (#4)
    Fabrication outputs move from the project root into fab/rev-1.0/, one
    folder per revision sent to fab, never regenerated in place.
    fab/rev-1.0/SOURCE.txt records the SHA-256 of the board they came from.
    scripts/check_fab_outputs.py regenerates the outputs and fails if the
    newest revision's committed files differ, when the board still matches
    SOURCE.txt; if the board has moved on it reports a notice and passes.
    Gerbers are compared by drawn geometry, because KiCad does not write
    primitives in a stable order (rev 1.0's front silkscreen lists the same
    strokes in a different sequence on every plot).
    fp-lib-table is r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
    [bazauto-block-detection-B_Cu.gbr, bazauto-block-detection-B_Mask.gbr, bazauto-block-detection-B_Silkscreen.gbr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]
